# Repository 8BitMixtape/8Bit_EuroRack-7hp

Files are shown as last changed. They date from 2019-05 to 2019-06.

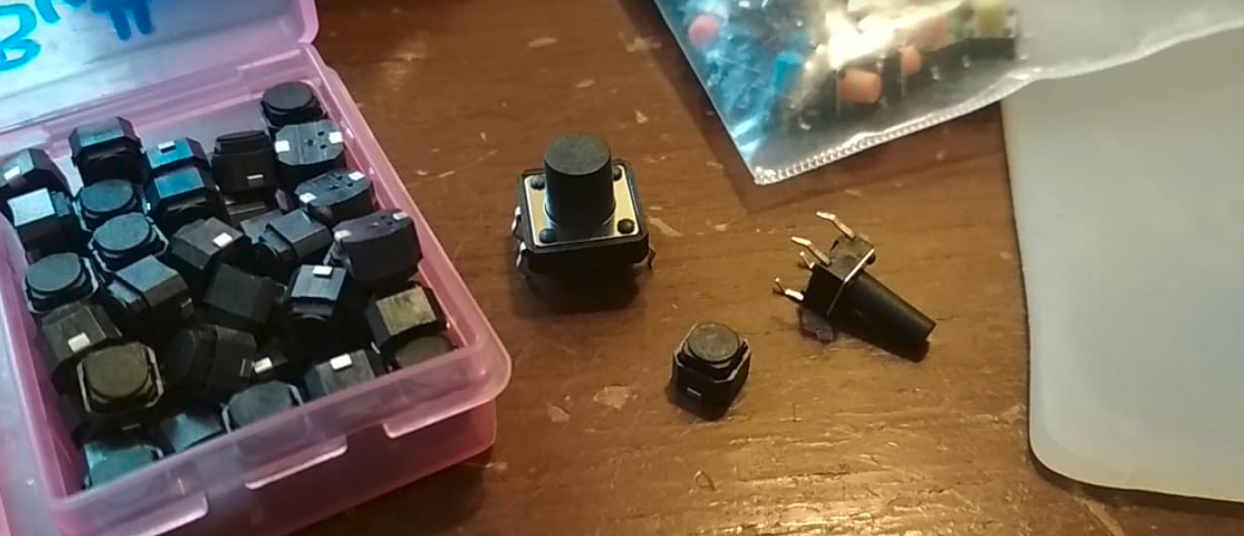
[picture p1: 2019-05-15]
parts/perfect_buttons.png

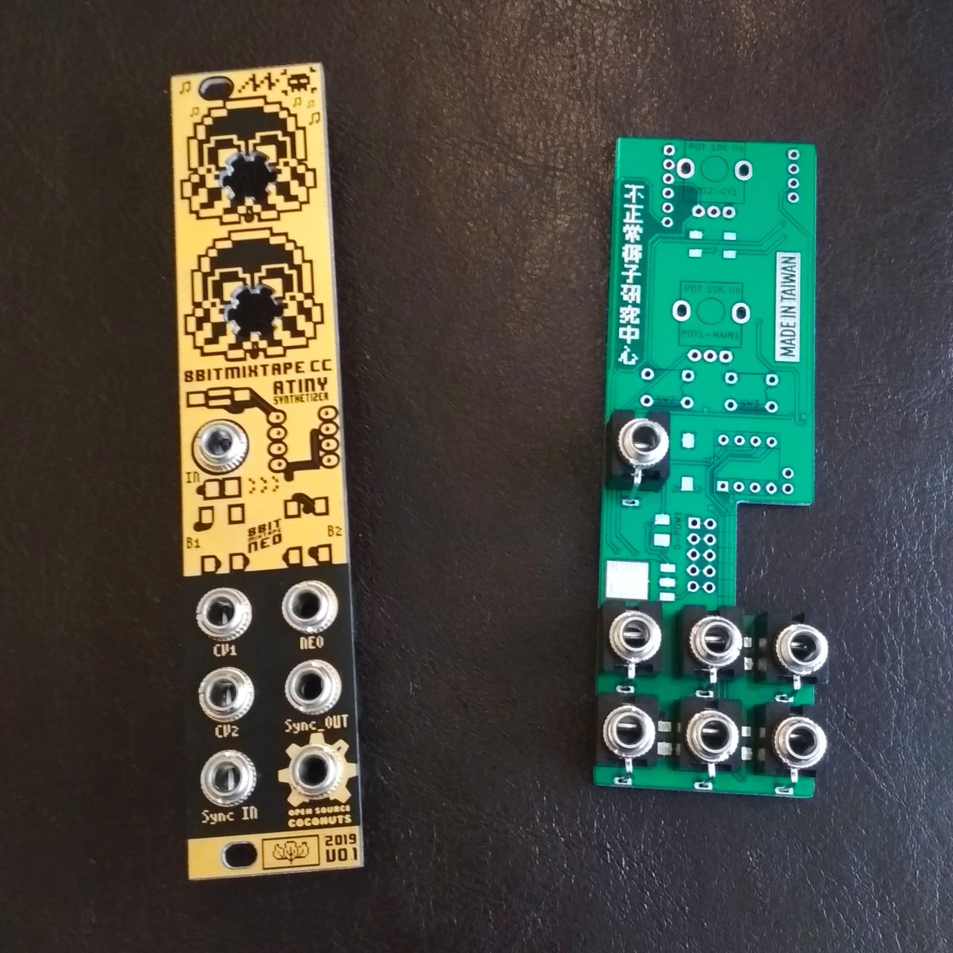
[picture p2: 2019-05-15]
photos/IMG_20190514_144135.jpg

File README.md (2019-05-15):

# 8Bit_EuroRack-7hp
8Bit Mixtape goes Modular!! Due to popular requests... adapted and improved the mixtape circuit to fit into standard Eurorack Modular format

Join and follow our discussion on the forum:

https://8bitmixtape.discourse.group/t/eurorack-rebooted/47/4

# Features

## 7hp more space for style!

## Two board design

Maybe the Eurorack scene like to have more this kinda standard double-decker style

## 0.1 Prototype - WORKING

### to improve

* Put 2 Neopixel und the potentiometers each
* switch position of Chip and Buttons to create more space between pot and buttons
* optimize position of jacks and pots (sub-millimeter improvements)
* What kinda buttons to use????
* create nice front plates
* anything else?

## Schematic

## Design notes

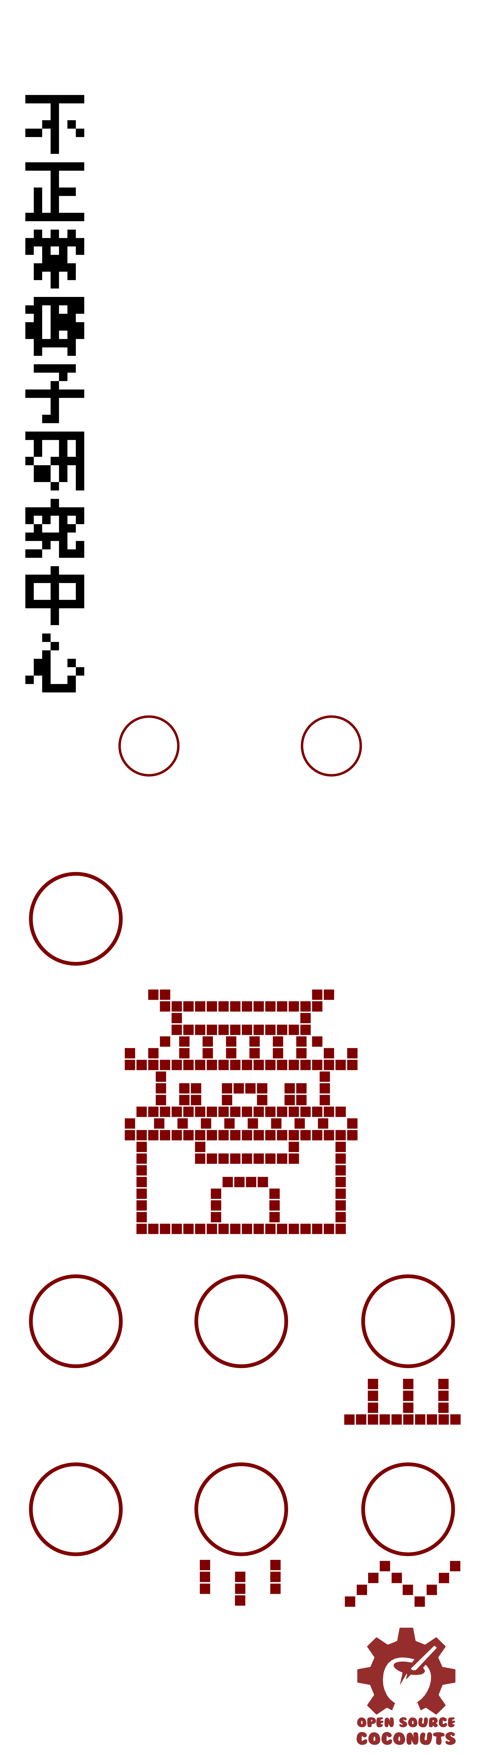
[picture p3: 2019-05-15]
frontplate/.svg2shenzhen-cache/images/F.Mask_g9831.png

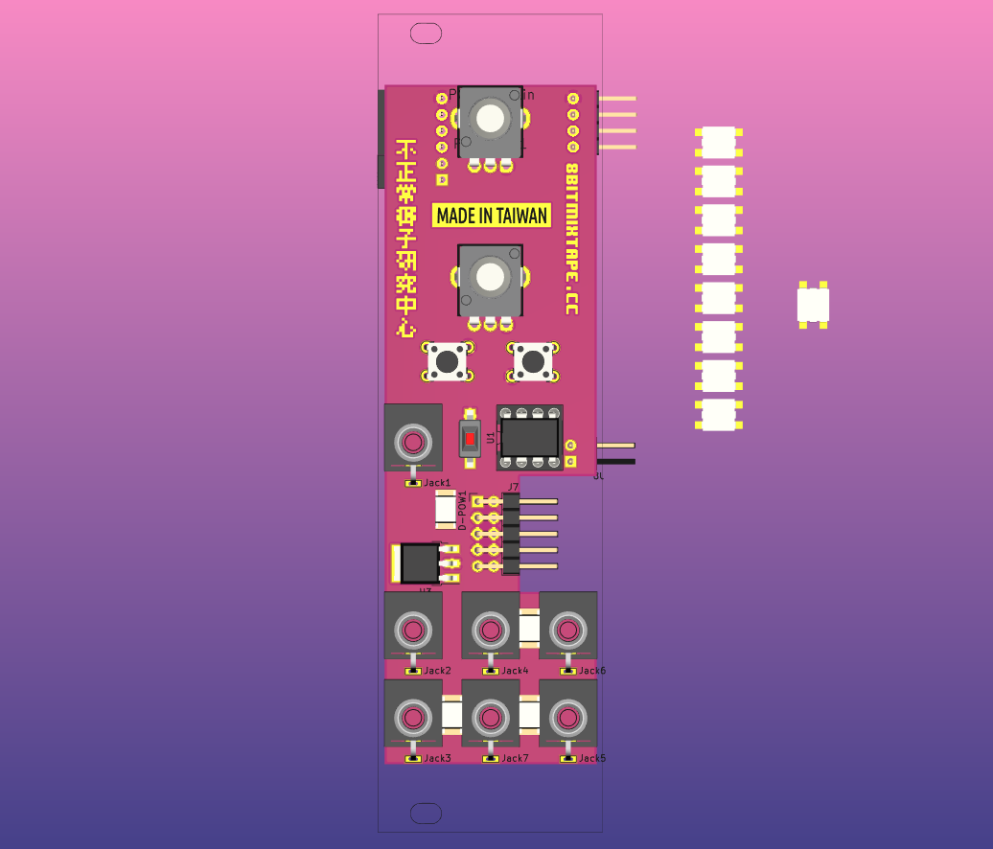
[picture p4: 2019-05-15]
photos/8bit_Eurorack_7hp_v03.png

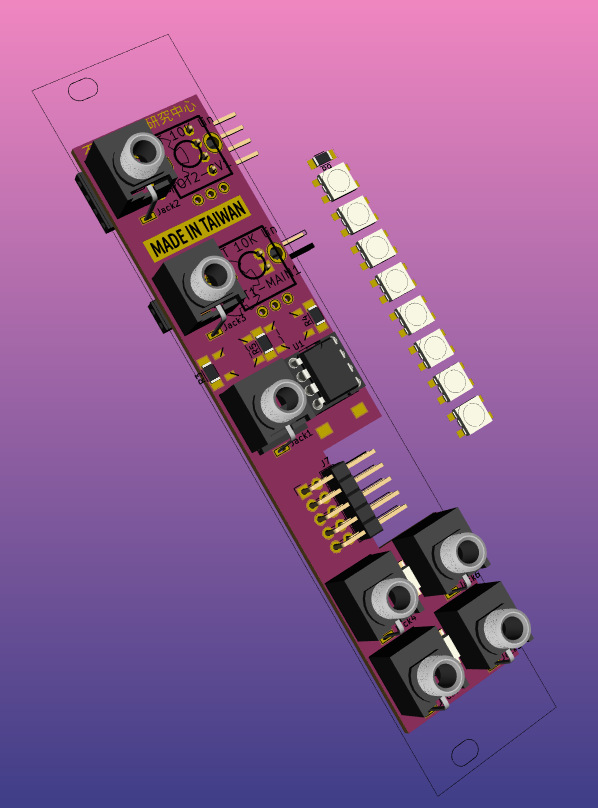
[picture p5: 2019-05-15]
photos/3d_render_8Bit_Mixtape_Eurorack_5hp.png

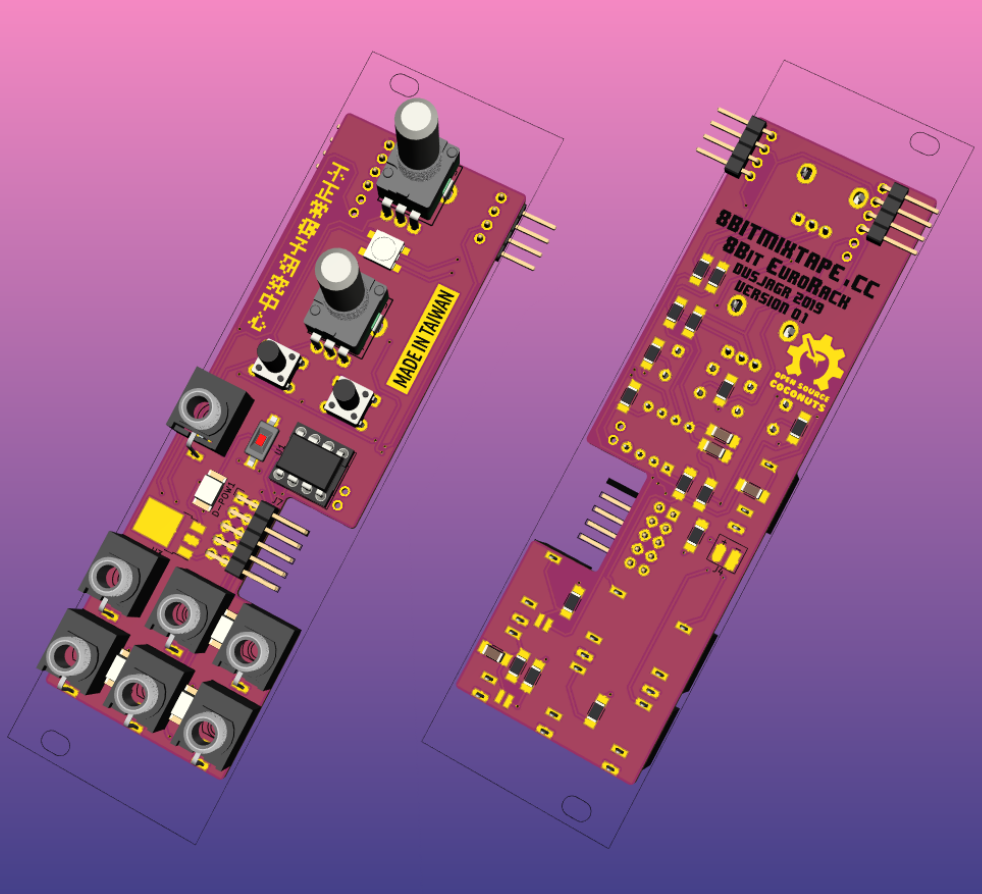
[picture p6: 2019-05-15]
photos/3d.coll.png

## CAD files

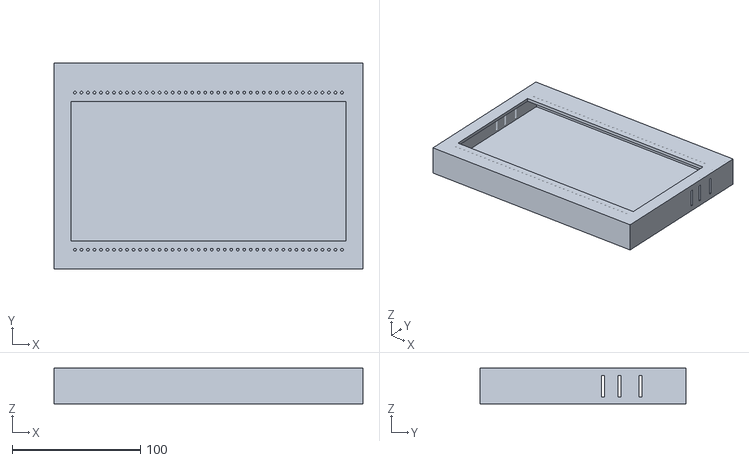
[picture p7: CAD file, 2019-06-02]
3d-case/mixtape_modular_Eurorack_42.stl
241.0 x 161.0 x 28.0

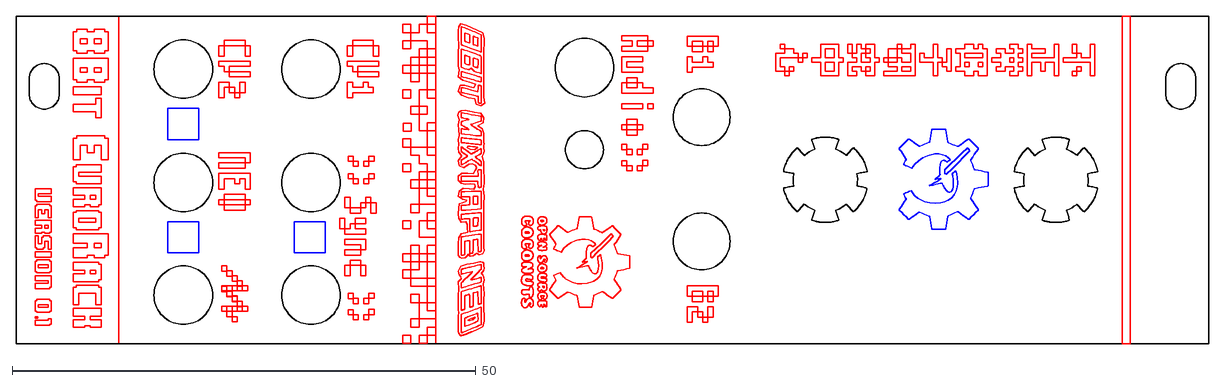
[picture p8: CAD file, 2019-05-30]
frontplate/7hp_frontplate_NEW_13.dxf
128.5 x 35.3

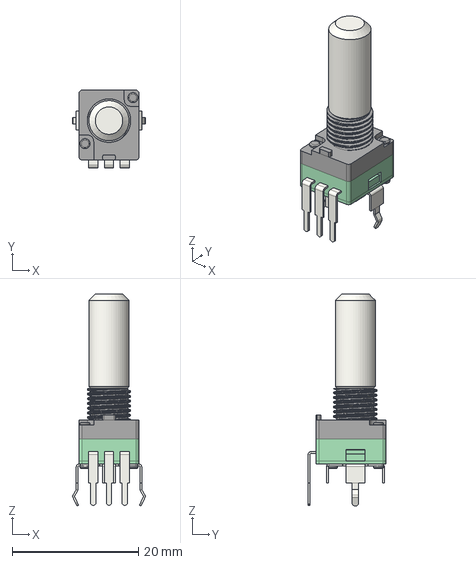
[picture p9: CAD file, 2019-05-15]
KiCAD/3d_models/ALPHA-RD901F-40.step
11.5 x 12.4 x 33.6 mm

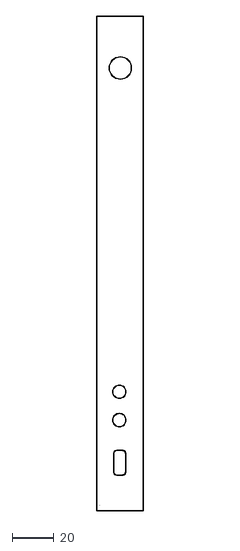
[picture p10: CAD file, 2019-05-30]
3d-case/back_cutout.dxf
22.1 x 236.5

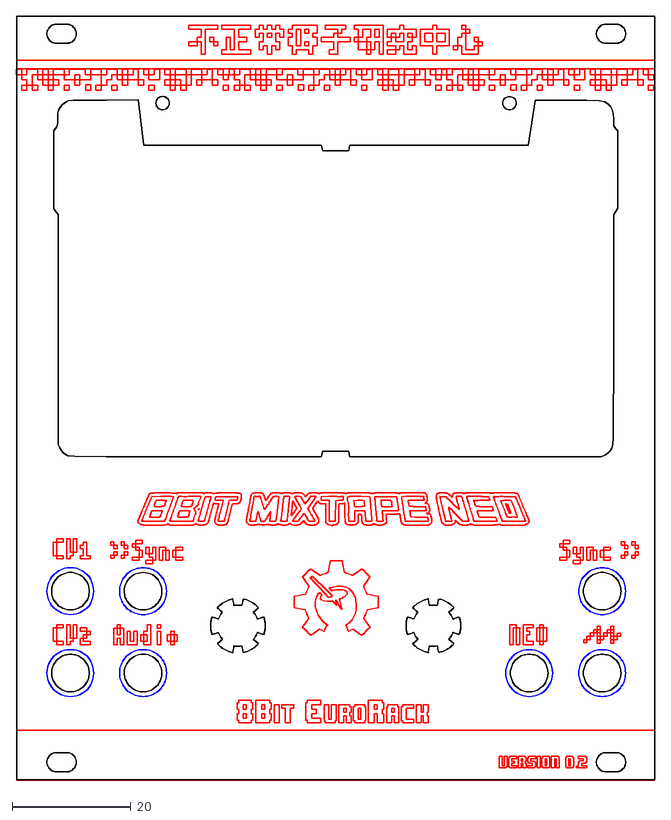
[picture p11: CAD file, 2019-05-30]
frontplate/dropIn_mixtapeModule_03.dxf
107.4 x 128.5

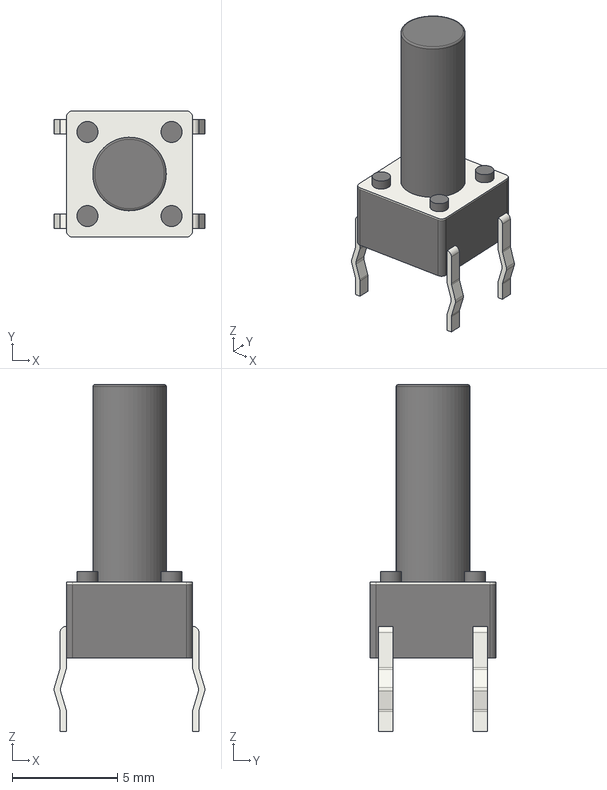
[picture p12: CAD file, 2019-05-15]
KiCAD/3d_models/SW_PUSH_6mm_H13mm.step
7.17 x 6.00 x 16.5 mm

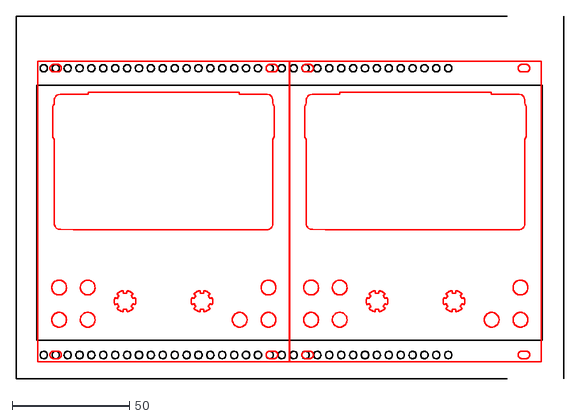
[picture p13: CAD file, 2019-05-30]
3d-case/right_cutout.dxf
233.8 x 154.7

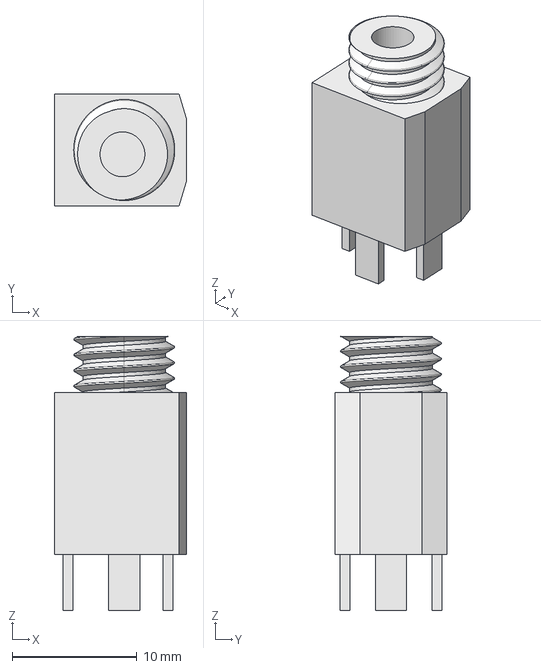
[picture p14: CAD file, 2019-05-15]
KiCAD/3d_models/PJ3410.step
10.6 x 9.00 x 22.0 mm

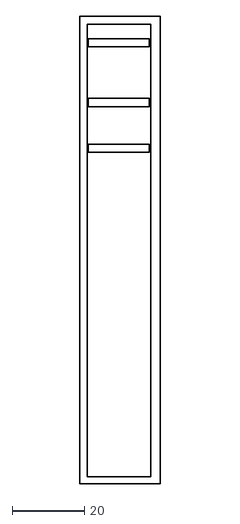
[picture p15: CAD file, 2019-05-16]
3d-case/top_cutout.dxf
22.3 x 129.7

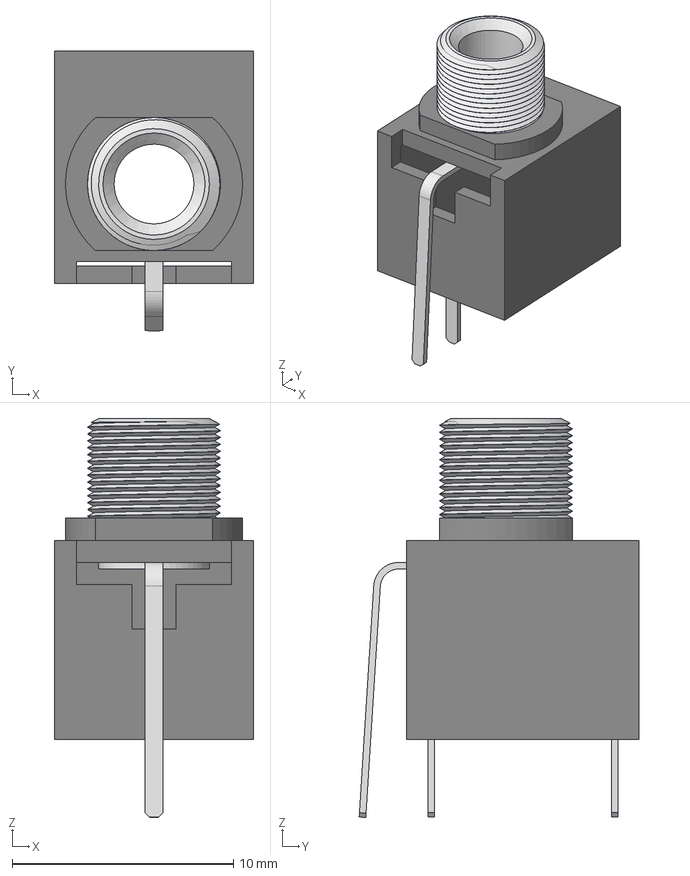
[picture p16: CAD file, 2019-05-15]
KiCAD/3d_models/PJ301M-12.step
9.00 x 12.6 x 18.0 mm

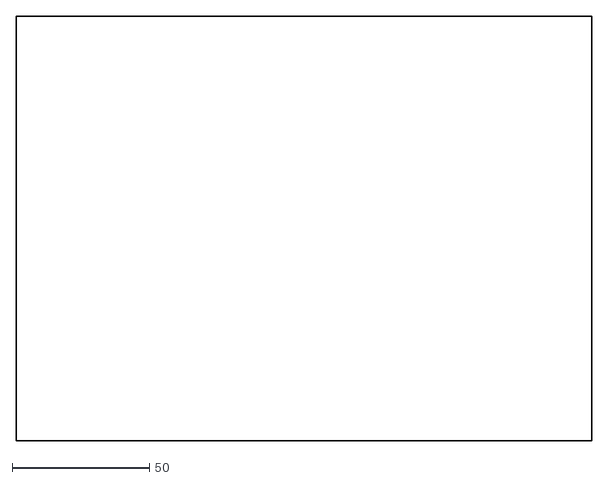
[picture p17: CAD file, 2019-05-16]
3d-case/left_cutout.dxf
209.7 x 154.7

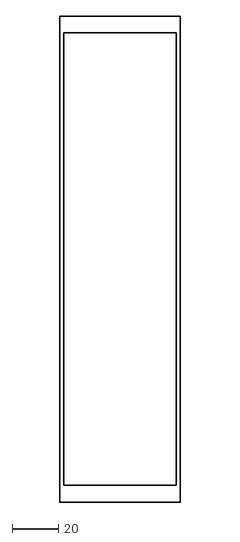
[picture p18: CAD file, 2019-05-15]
3d-case/front_cutout.dxf
52.0 x 209.5

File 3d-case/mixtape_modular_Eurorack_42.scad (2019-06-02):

/*
benjolin case
by stahl
[office@stahlnow.com]

released under the permissive MIT license

file history
v1.0 - born
v2.0 - edits by dusjagr flip top right chaos
v2.1 - customized for 42hp eurorack
*/

/*********************************************** START OF USER VARIABLES */

// what to build
//translate ([99,-37,-7]) rotate([180, 0, 180])mixtape();
rotate([0, 90, 0]) 3d(); // 3d model
//laser(); // uncomment for laser cutting

// define inner volume in mm
length = 155; 
width = 22;
height = 235; // spacer + board + spacer + little extra

thickness = 3; // thickness of material

hp = 42;
moduleScrew = 2.2;

// slots configuration
slots = true; // make slots?

// overlap of top/bottom panels in mm
overlap = 0;
// round edge or not (applies only if overlap > 0)
round_edges = true;

// slots configuration55555
num_slots_right_left = 4;       // number of slots >= 0
slot_width_right_left = 5;     // width of slot
slot_clearance_right_left = 10;  // inset to slot >= 0, add plus or minus 0.1 if last tooth is missing
num_slots_front_back = 2;       
slot_width_front_back = 5;
slot_clearance_front_back = 6;  // inset to slot >= 0, add plus or minus 0.1 if last tooth is missing

// t-joints configuration
t_joints_front = false;
t_joints_back = false;
t_joints_right = false;
t_joints_left = false;
t_joints_top_bottom = false;

num_t_joints = 2; // number of t-joints
bolt_size = 3; // bolt size in mm (M2,M3,M4,M5, etc.)
bolt_length = 12; // bolt length in mm

// clearence between panel edge and t-joint
// could be set to a number instead of calculation
t_joints_top_left_clearance = length/(2*num_t_joints); 
t_joints_right_left_clearance = height/(2*num_t_joints);
t_joints_front_back_clearance = width/(2*num_t_joints);

joints_inset = 2; // clearance between panel edge and hole
nut_size = 7.5;// M3: 5.5, M4: 7.2, M5: 8.0
nut_thickness = 3.5;// M3: 2.4, M4: 3.5 M5: 5.6

// clearance for laser cutting in mm
laser_clearance = 5;

// colors
col_alpha = 1;
col_top =  "DeepPink";
col_bottom = "DeepPink";
col_left = "Peru";
col_right = col_left;
col_front = "Brown";
col_back = col_front;

// number of fragments for round edges
$fn = 30;

glitch_corr = 0.1; // visual glitch correction (careful, this will mess with dimensions!)

/************************************************* END OF USER VARIABLES */

module 3d() { 
    top();
    bottom();
    front();
    back();
    left();
    right();

}


module laser() {
    glitch_corr = 0.0; // set glitch correction to zero
    // top
    rotate([0, 0, 180])
    if (slots) {
        projection() difference() {
            top();
            right();
            left();
            slots_front_back(-(length+thickness)/2.0);
            slots_front_back((length+thickness)/2.0);
        }
    } else {
        projection() mirror([1,0,0]) top();
    }

    // bottom
    bottom_offset = -(length+2*thickness+2*overlap+laser_clearance);
    translate([0,bottom_offset,0])
    rotate([0, 0, 180]) mirror([1,0,0])
    
    if (slots) {
        projection() difference() {
            bottom();
            right();
            left();        
            slots_front_back(-(length+thickness)/2.0);
            slots_front_back((length+thickness)/2.0);
        }
    } else {
        projection() bottom();
    }
    
    // front
    front_offset = bottom_offset-(length+height)/2-overlap-2*thickness-laser_clearance;
    projection() translate([0,front_offset,0]) rotate([-90,0,180])
    
    if (slots) {
        difference() {
            front();
            slots_right_left(-(width+thickness)/2);
            slots_right_left((width+thickness)/2);
        }
    } else {
        projection() front();
    }
    
    
    // back
    back_offset = front_offset-height-2*thickness-laser_clearance;
    projection() translate([0,back_offset,0]) rotate([-90,0,180]) mirror([1,0,0]) 
    if (slots) {
        difference() {
            back();
            slots_right_left(-(width+thickness)/2);
            slots_right_left((width+thickness)/2);
        }
    } else {
        projection() back();
    }

    // left
    left_offset = back_offset-height-2*thickness-laser_clearance;
    projection() translate([0,left_offset,0]) rotate([0,90,90]) left();
    
    // right
    right_offset = left_offset-height-2*thickness-laser_clearance;
    projection() translate([0,right_offset,0]) rotate([0,-90,90]) right();
    
}


module top() {
    if (round_edges) {
        p = 0;
    } else {
        p = overlap;
    }
    
    difference() {
        union() color(col_top, col_alpha) {
            minkowski()
            {
                translate([0,0, (height+thickness)/2])
                if (!round_edges) {
                    cube([width+2*thickness+overlap, length+overlap+2*thickness, thickness-0.01], center=true);
                } else {
                    cube([width+2*thickness, length+2*thickness, thickness-0.01], center=true);
                }
                if (round_edges) cylinder(r=overlap, h=0.001, $fn=100);
            }
        }
        t_joints_holes_top_bottom();
        t_joints_holes_front_back();       
        // cutouts
        color("silver")
        translate([-width/2, -length/2, (height-thickness)/2])
        linear_extrude(thickness*3)
        import(file = "top_cutout.dxf", layer = "0");
        //engraving
        color("white")
        translate([0.0, 0.0, height/2])
        linear_extrude(thickness)
        import(file = "top_cutout.dxf", layer = "engraving");
    }
}

module bottom() {
    if (round_edges) {
        p = 0;
    } else {
        p = overlap;
    }
    
    difference() {
        union() color(col_bottom, col_alpha) {
            minkowski()
            {
                translate([0,0, -(height+thickness)/2])
                if (!round_edges) {
                    cube([width+2*thickness+overlap, length+overlap+2*thickness, thickness-0.01], center=true);
                } else {
                    cube([width+2*thickness, length+2*thickness, thickness-0.01], center=true);
                }
                if (round_edges) cylinder(r=overlap, h=0.001, $fn=100);
            }
        }
        t_joints_holes_top_bottom();
        t_joints_holes_front_back();
        // cutouts
        color("silver")
        translate([-width/2, -length/2, -height/2-1.5*thickness])
        linear_extrude(thickness*2)
        import(file = "bottom_cutout.dxf", layer = "0");
    }
   
}

module front() { 
    difference() {
        union() color(col_front, col_alpha) {
            translate([0.0, -(length+thickness)/2.0, 0.0])
            cube([width+2.0*thickness, thickness, height], center=true);
            // slots
            if (slots)
                slots_front_back(-(length+thickness)/2.0);
        }
        
        // t-joints
        if (t_joints_front)
            t_joints_front_back(-(length+thickness)/2.0);
        // t-joints holes (on the side)
        t_joints_holes_right_left();
        
        // cutouts
        color("silver")
        translate([-width/2,-length/2+thickness-0.1,-height/2]) rotate([90,0,0])
        linear_extrude(thickness*4)
        import(file = "front_cutout.dxf", layer = "0");   
    }
}

module back() {
    difference() {
        union()
        color(col_back, col_alpha) {
            translate([0.0, (length + thickness)/2.0, 0.0])
            cube([width+2.0*thickness, thickness, height], center=true);
            if (slots)
                slots_front_back((length+thickness)/2.0);
        }
        
        // t-joints
        if (t_joints_back)
            t_joints_front_back((length+thickness)/2.0);
        // t-joints holes (on the side)
        t_joints_holes_right_left();
        
        // cutouts
        color("silver")
        translate([-width/2,length/2-0.1,height/2]) rotate([-90,0,0]) 
        linear_extrude(thickness*2)
        import(file = "back_cutout.dxf", layer = "0");        
    }
}

module t_joints_holes_right_left() {
    if (t_joints_left)
        t_joints_right_left(-(width+thickness)/2.0+joints_inset, true);
    if (t_joints_right)
        t_joints_right_left((width+thickness)/2.0-joints_inset, true);
}

module t_joints_holes_top_bottom() {
    if (t_joints_top_bottom) {
        t_joints_top_bottom(-(width+thickness)/2.0+joints_inset, true);
        t_joints_top_bottom((width+thickness)/2.0-joints_inset, true);
    }
}

module t_joints_holes_front_back() {
    if (t_joints_front)
        t_joints_front_back(-(length+thickness)/2.0+joints_inset, true);
    if (t_joints_back)
        t_joints_front_back((length+thickness)/2.0-joints_inset, true);
}

module slots_front_back(d) {
    of = slot_width_front_back/2.0-thickness + slot_clearance_front_back;
    for (z = [-(height+thickness)/2.0 : height+thickness : (height+thickness)/2.0 ])
        for (x = [-width/2.0+of: (width-(2.0*of))/(num_slots_front_back-1.0) : width/2.0-of])
            translate([x, d, z])
            cube([slot_width_front_back, thickness, thickness], center=true);
}
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

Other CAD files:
3d-case/mixtape_modular_Eurorack_42.dxf

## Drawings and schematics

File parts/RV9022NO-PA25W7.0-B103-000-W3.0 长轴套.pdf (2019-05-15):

## 280° Rotation

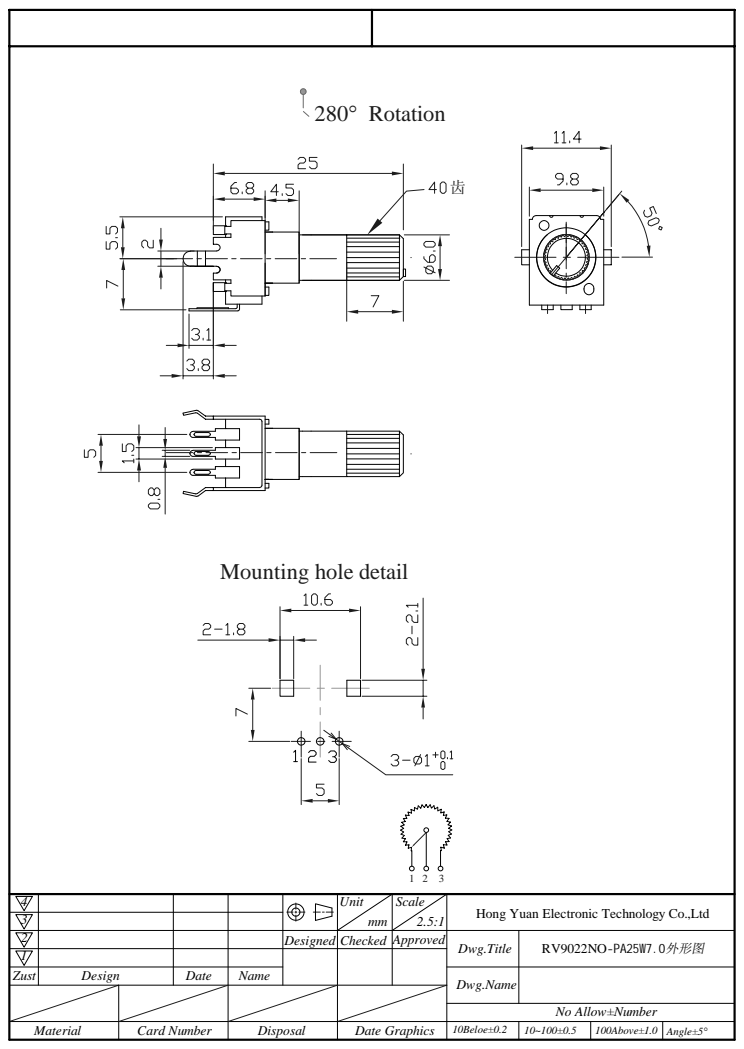
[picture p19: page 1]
Angle±5°; 100Above±1.0; 10Beloe±0.2; Dwg.Name; Dwg.Title; RV9022NO-PA25W7.0外形图

Mounting hole detail

4 | | Designed Checked | Unit | Scale 2.5:1 Approved | Hong Yuan Electronic Technology Co.,Ltd No Allow±Number
3 2

Zust Design | Date | Name

Material | Card Number | Disposal Date Graphics

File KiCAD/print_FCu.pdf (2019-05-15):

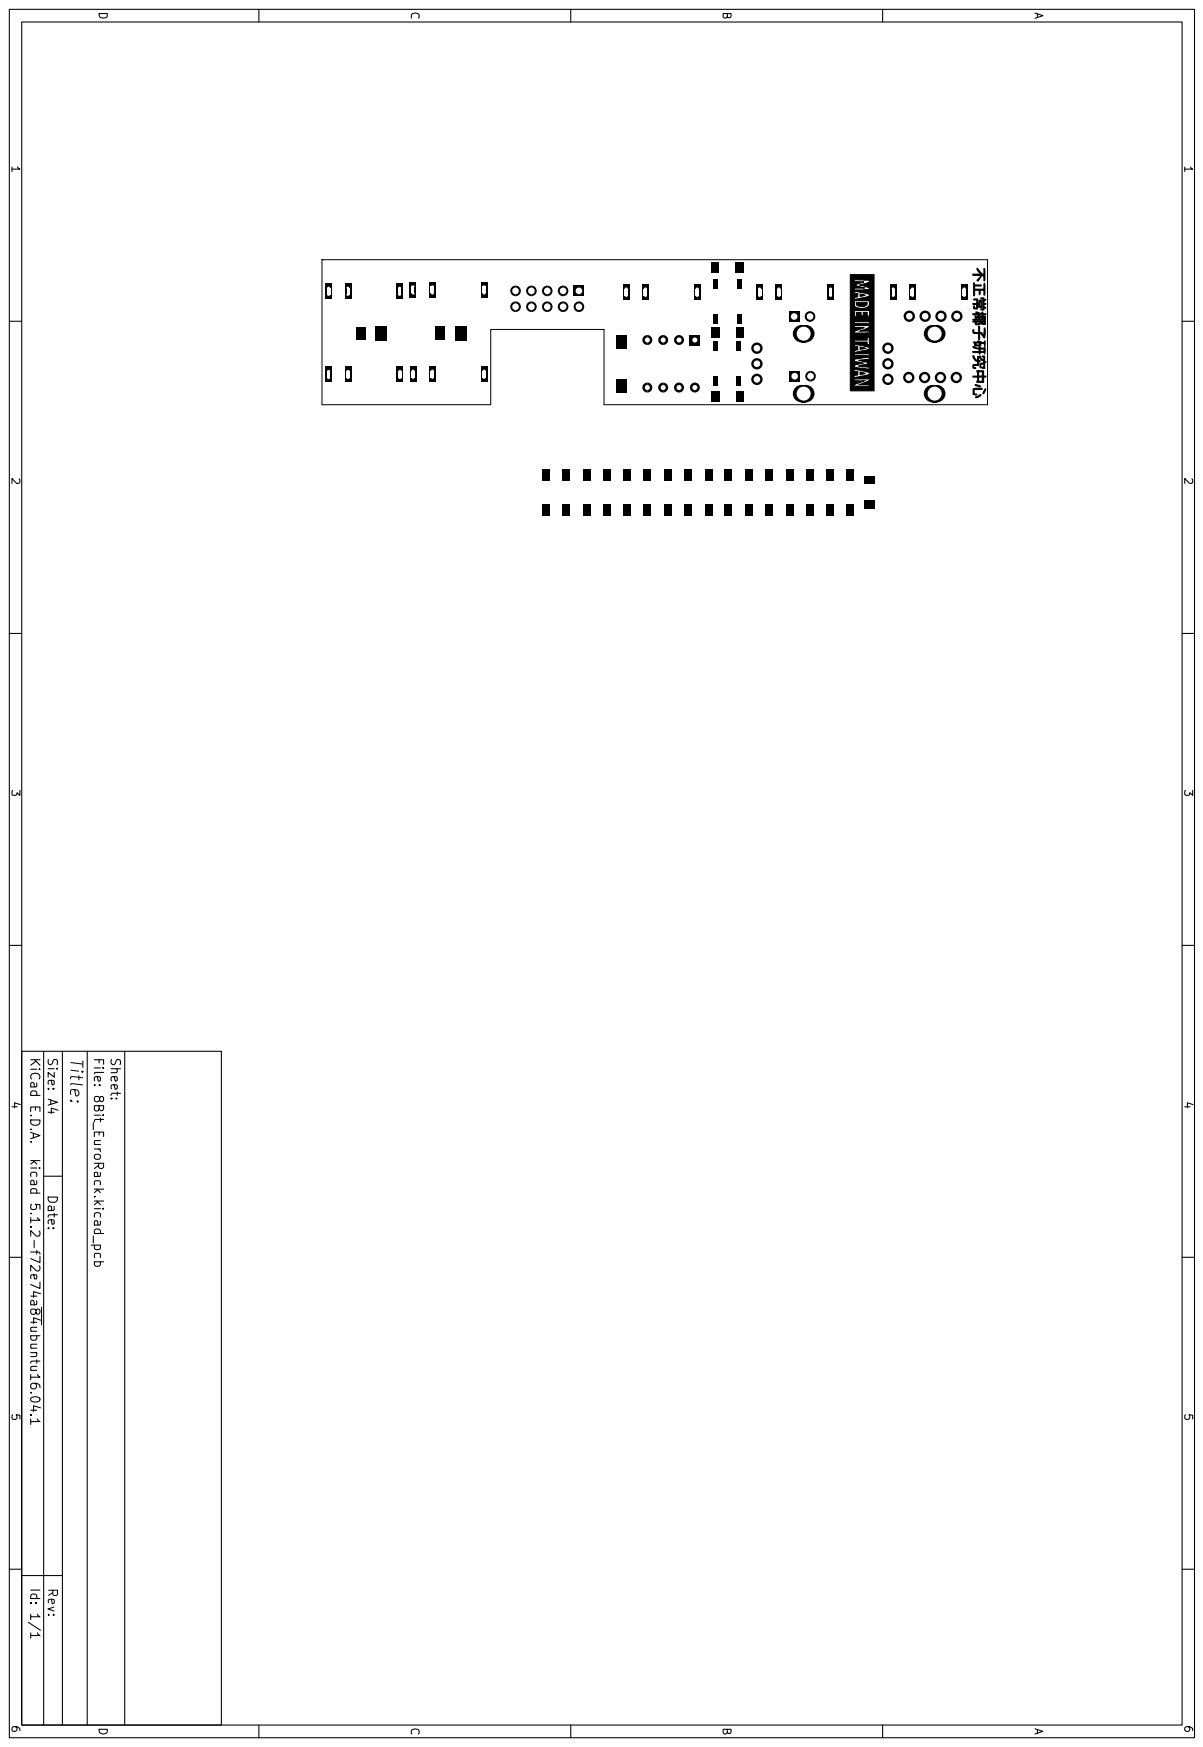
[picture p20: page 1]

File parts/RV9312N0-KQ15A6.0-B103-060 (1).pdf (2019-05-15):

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

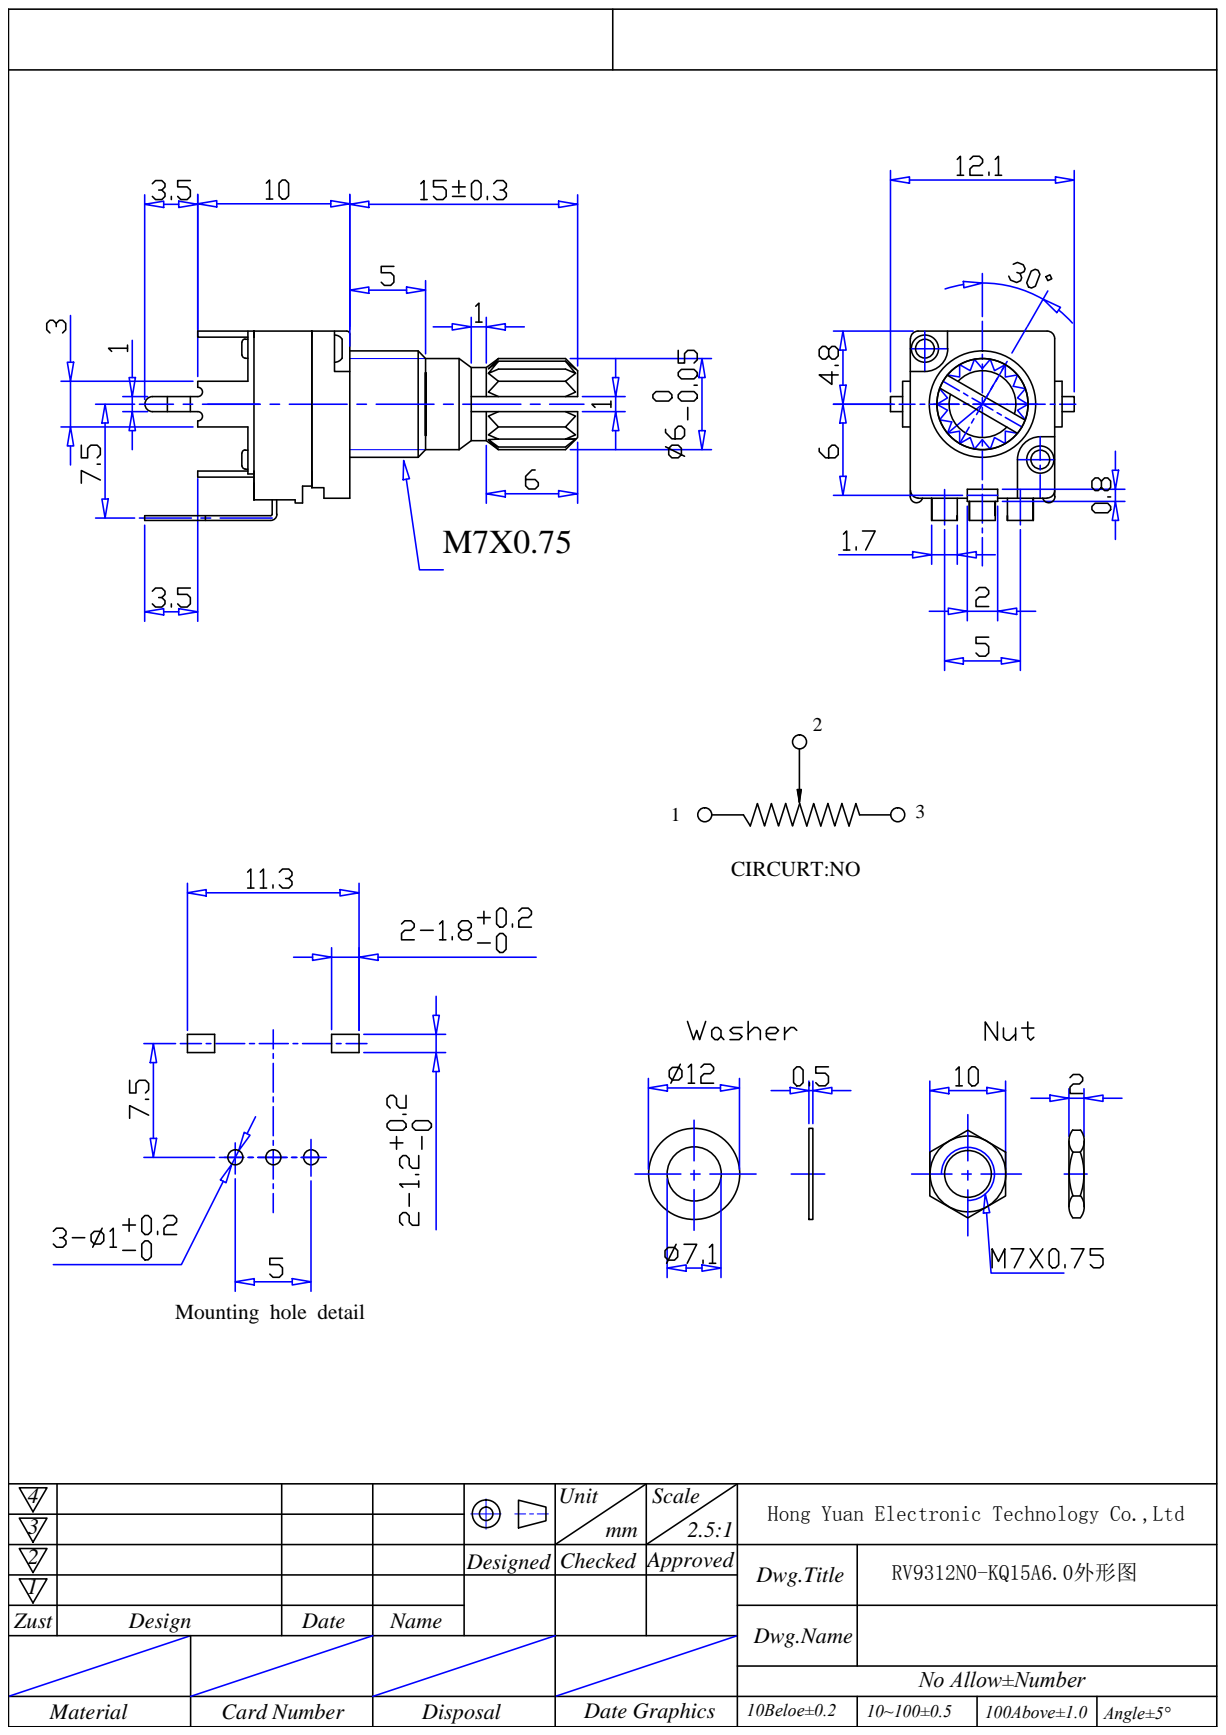
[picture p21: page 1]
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

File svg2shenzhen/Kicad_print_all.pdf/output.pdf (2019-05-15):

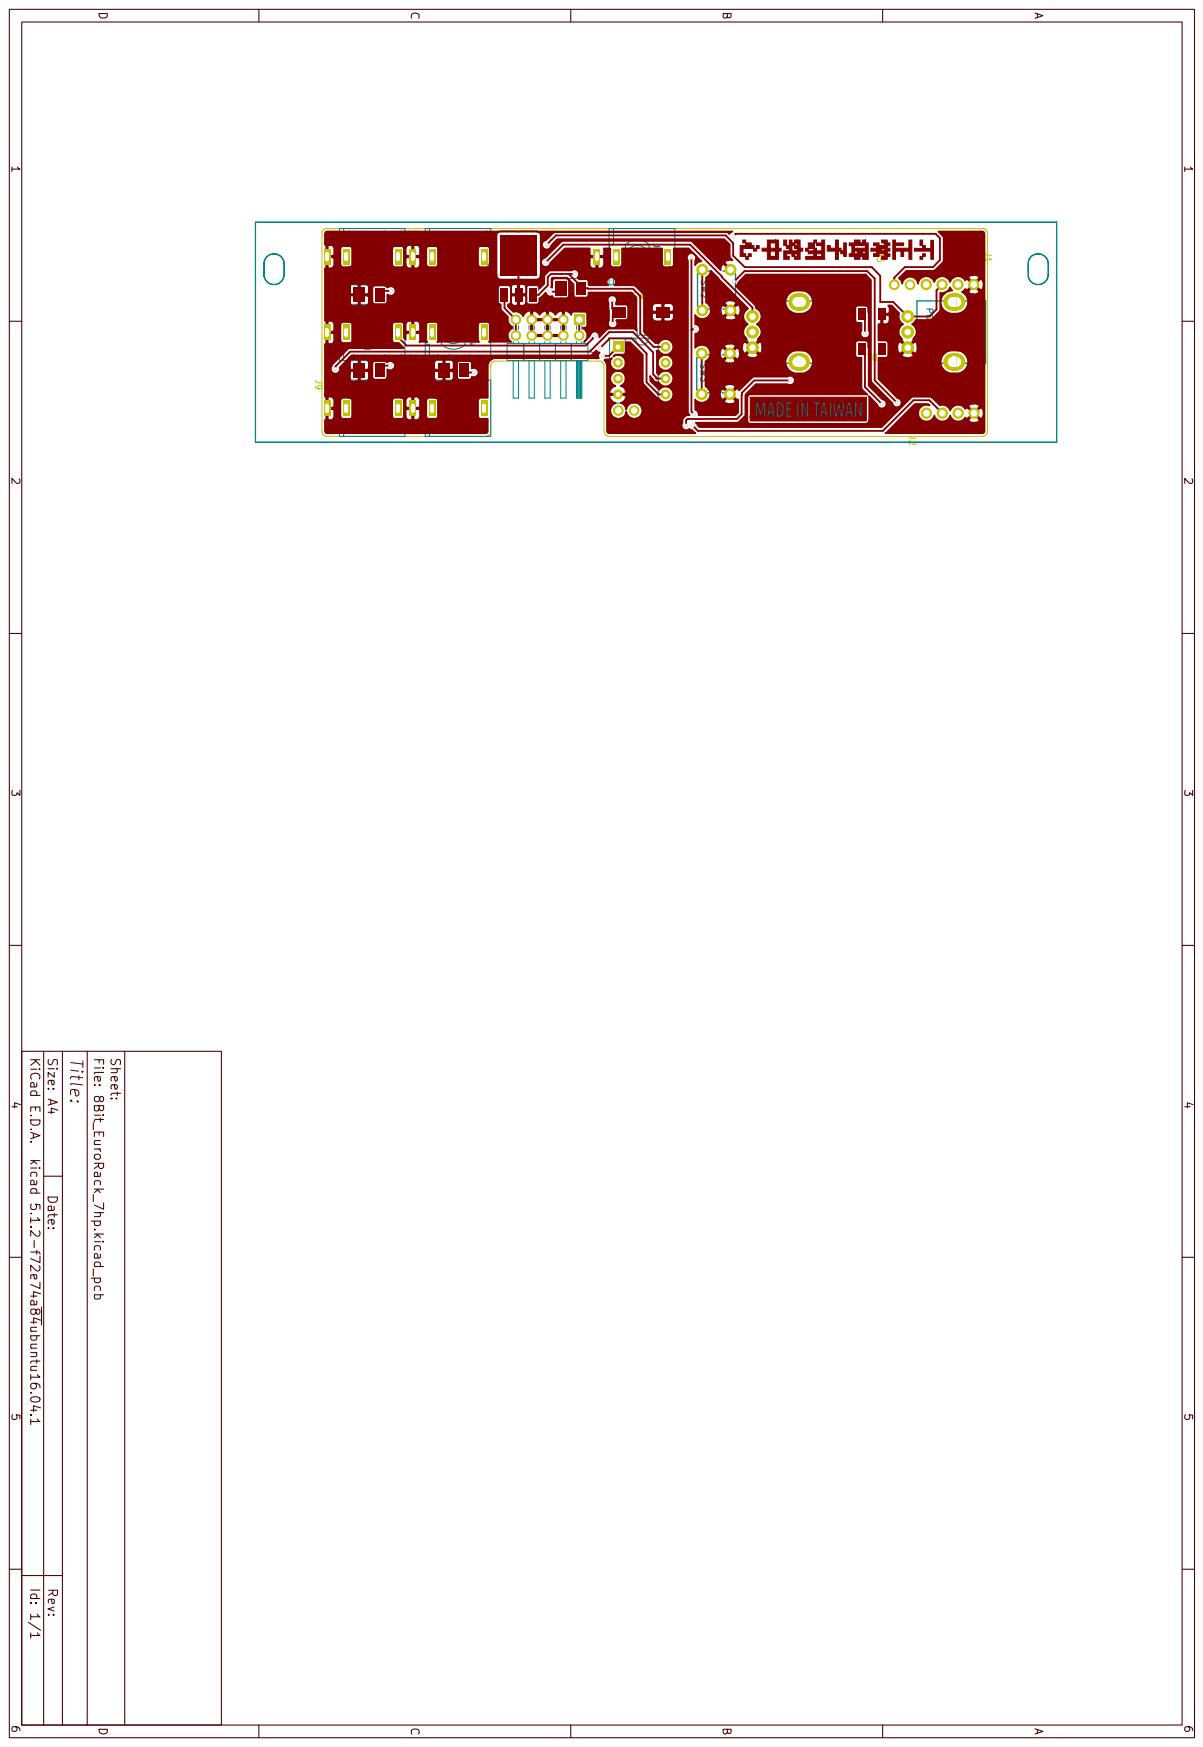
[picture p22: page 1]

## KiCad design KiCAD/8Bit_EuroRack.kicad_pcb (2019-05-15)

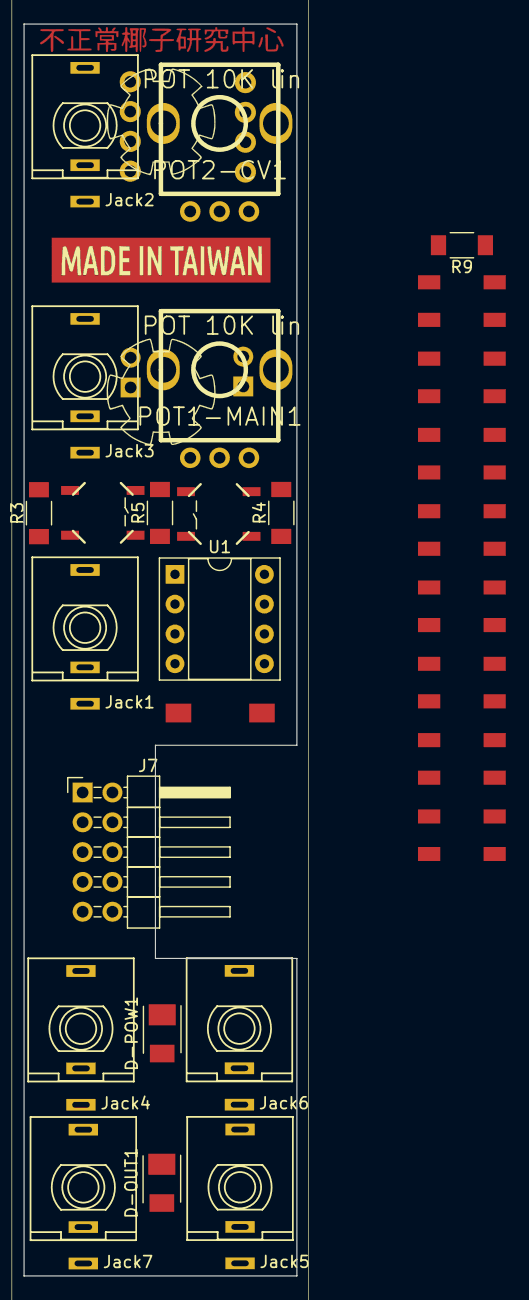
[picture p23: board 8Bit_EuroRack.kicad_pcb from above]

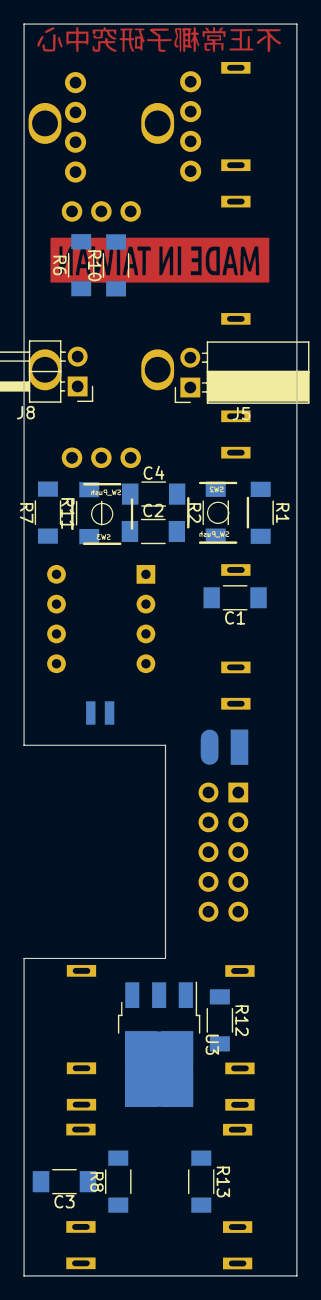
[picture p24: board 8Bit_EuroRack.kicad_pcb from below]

Board: 2 copper layers, 23.2 x 106.7 mm, 49 parts (18 on the bottom side), 29 nets, no tracks yet.

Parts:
C1, C2, C3: 100nF; C_1206_3d
C4: 10uF; C_1206_3d
D1, D2, D3, D4, D5, D6, D7, D8: SK6812; Mixtape_NEO_WS2812B_3d
D-OUT1: LED; LED_PLCC_2835_Handsoldering
D-POW1: LED; LED_PLCC_2835_Handsoldering
J1, J2: CONN_01X04; Angled_1x04_Pitch2.54mm-3d
J4: Con_3-5V; Bat_connector_SMD
J5: Conn_01x02; Socket_Strip_Angled_1x02_Pitch2.54mm
J6: Sync_Jumper; Sync_jumper
J7: Conn_02x05_Odd_Even; Pin_Header_Angled_2x05_Pitch2.54mm_with_space_for_con
J8: Conn_01x02; Pin_Header_Angled_1x02_Pitch2.54mm
Jack1, Jack2, Jack3, Jack4, Jack5, Jack6, Jack7: JACK_2P; PJ301M-12_stahl
POT1-MAIN1, POT2-CV1: POT 10K lin; RD901F-ALPHA-3D
R1, R2, R3, R4, R5: 22k; R_1206_3d
R6, R7: 22K; R_1206_3d
R8, R9: 330; R_1206_3d
R10, R11: 4.7K; R_1206_3d
R12, R13: 1K; R_1206_3d
SW2, SW3: SW_Push; TACTILE-SWITCH-SMD
SW4: SW_Push; SW_SPST_FSMSM
U1: ATTINY85-20SU; DIP-8_W7.62mm_Socket
U3: 7805; TO-252-3_TabPin2
board1: SVG2SHENZHEN; 8Bit_EuroRack-NEO

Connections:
+3V3: C2.1, C4.1, D1.3, D2.3, D3.3, D4.3, D5.3, D6.3, D7.3, D8.3, D-POW1.2, J1.3, J2.2, J4.2, R1.1, R10.1, R11.1, U1.8
AudioProg: C1.1, J5.1, Jack1.1
But-L: R3.2, SW2.1
But-R: R4.2, R5.2, SW3.1
CV1_IN: J1.2, Jack2.1, POT2-CV1.1, R10.2
CV2_IN: J5.2, Jack3.1, POT1-MAIN1.1, R11.2
CV_OUT: C3.1, J8.2, Jack5.1, R8.1
DC_in: J7.1, J7.2
GND: C2.2, C3.2, C4.2, D1.1, D2.1, D3.1, D4.1, D5.1, D6.1, D7.1, D8.1, D-OUT1.1, J1.4, J2.1, J4.1, J7.3, J7.4, J7.5, J7.6, J7.7, J7.8, Jack1.3, Jack2.3, Jack3.3, Jack4.3, Jack5.3, Jack6.3, Jack7.3, POT1-MAIN1.3, POT2-CV1.3, R2.2, R12.2, SW2.2, SW3.2, SW4.2, U1.4
unnamed: D1.2, R9.1
unnamed: D1.4, D2.2
unnamed: D2.4, D3.2
unnamed: D3.4, D4.2
unnamed: D4.4, D5.2
unnamed: D5.4, D6.2
unnamed: D6.4, D7.2
unnamed: D7.4, D8.2
unnamed: D-OUT1.2, R13.2
unnamed: D-POW1.1, R12.1
unnamed: J6.1, SW4.1, U1.1
unnamed: J7.9, J7.10
unnamed: POT1-MAIN1.2, R7.2
unnamed: POT2-CV1.2, R6.2
PB0: J8.1, Jack7.1, R9.2, U1.5
PB1: J2.3, R8.2, R13.1, U1.6
PB2/A1: R7.1, U1.7
PB4/A2: R6.1, U1.3
Sync_IN: C1.2, J1.1, Jack4.1, R1.2, R2.1, R3.1, R4.1, R5.1, U1.2
Sync_OUT: J2.4, J6.2, Jack6.1

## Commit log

2019-05-15 all files for v0.v0.1
    [7hp_modle_01.dxf, 8Bit_EuroRack-2019-05-06-14-48-04.sch, 8Bit_EuroRack-NEO_7hp_frontplate_01.kicad_pcb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]
2019-05-16 frontplate designs
    [back_cutout.dxf, bottom_cutout.dxf, left_cutout.dxf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]
2019-05-30 adding new 3d files for case
    [7hp_frontplate_NEW_11.dxf, 7hp_frontplate_NEW_12.dxf, 7hp_frontplate_NEW_13.dxf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]
2019-06-02 small changes on case
    [mixtape_modular_Eurorack.dxf, mixtape_modular_Eurorack_42.dxf, mixtape_modular_Eurorack_42.scad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]
